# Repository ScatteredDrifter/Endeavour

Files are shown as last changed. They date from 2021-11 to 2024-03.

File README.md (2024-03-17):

# Endeavour | 10 Ortho Keyboard

An orthogonal  10u keyboard heavily inspired by [kb_elmo`s QEZ](https://github.com/kb-elmo/QEZ)

Used License for this project :: [Cern Open Hardware](/LICENSE)
by Evelyn~ Scattered Drifter 

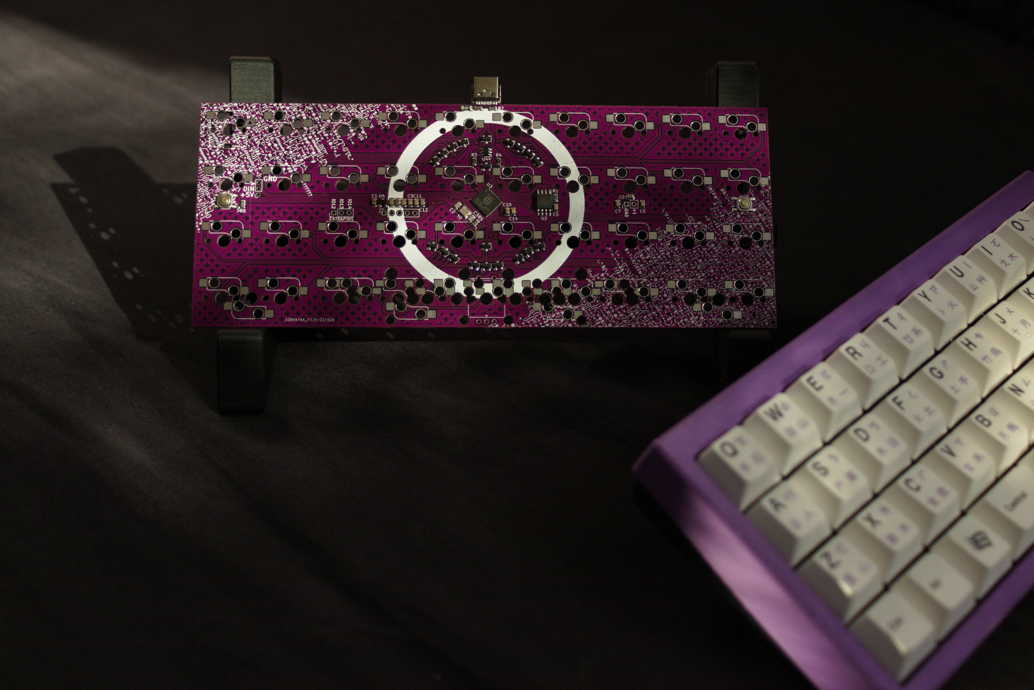
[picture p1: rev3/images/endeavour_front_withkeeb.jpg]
image of pcb with built keyboard


---

### Current Status: 

- rev3 tested, minor issues fixed in 
- firmware for QMK was updated to newest version, can be found [here](https://github.com/ScatteredDrifter/vial-qmk/tree/scatteredDriftersBoards/keyboards/scattereddrifter/endeavour)
- ZMK firmware pending
- rev3 case available - yet I dislike it in its current state.

---

## Endeavour V³ released //
The third iteration introduced a complete redesign of the pcb primarily to accommodate the **RP2040** and **BAV70 diodes**.

 I tried creating a circular positioning pattern for the components where their center is set with the mcu itself. Due to reposition of every component I rerouted the whole board again; also because Endeavour V¹ was one of my first designs and you can tell it was. A new silkscreen for both front and back of the pcb sets a different theme and clutters the whole board with ASCII-rubbish. This came into my mind because any actual drawing or pattern idea I had was blocked by my miserable ability to create art.

A new **case** accompanies this revision. Its not entirely done neither am I satisfied with its look and design. My abilities with CAD are limited and I lack the endurance ( will to use Windows or learn an alternative software) and time to make a better one or to create an actual good / decent design. 

Nevertheless my current process is shared in [this folder](/cases_rev3).
I've **tested the case** with a previous rev pcb and could verify that its mostly working. 
The new **case utilizes tadpole mount** of some sort hence I **ought to write a build guide**. 

For the previous versions of the **PCB** and **Case** look at the folders below:

2. [Rev2](/rev2/rev2.md)

### Features |- Rev3:
- support for two encoders ( top left)(bottom row middle)
- RP2040 
- 3 IO Pins exposed via breakout 
- pinout for led-strip (WS28 and similarly supported)
- QMK / VIAL support ( zmk should be possible too ) 
- different layout options
- new **case** with tadpole mount

#### Layout:

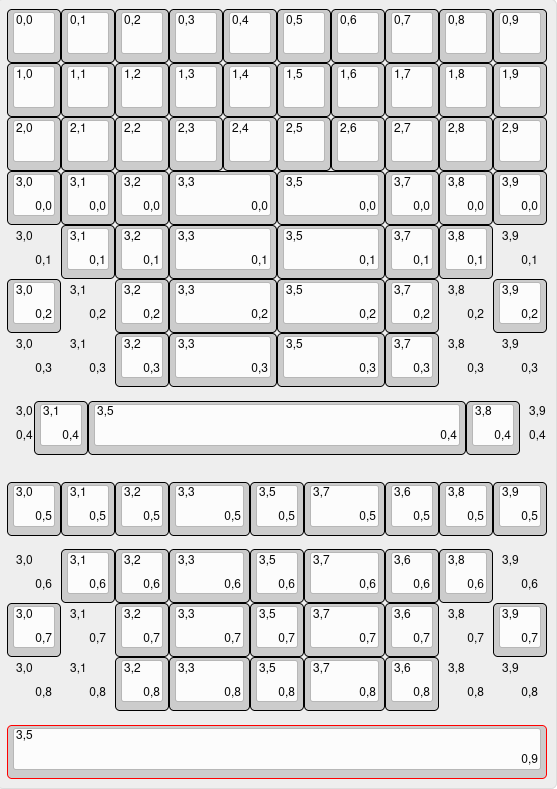
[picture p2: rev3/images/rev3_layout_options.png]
Image of available layouts in third revision


---

## Images 

### Images of V³ PCB:

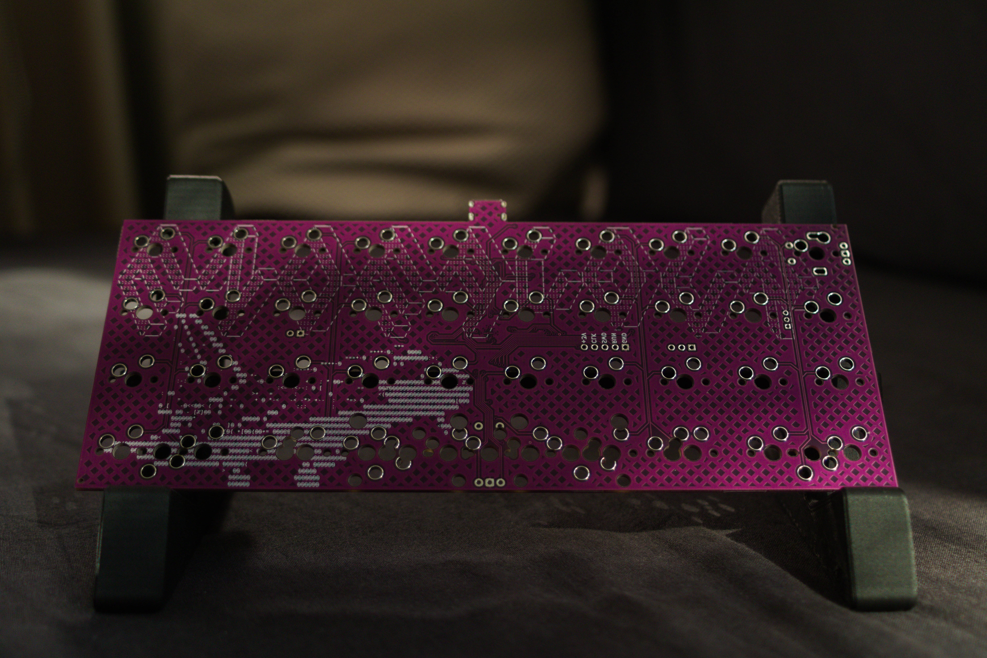
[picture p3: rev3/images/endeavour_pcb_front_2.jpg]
front image of pcb


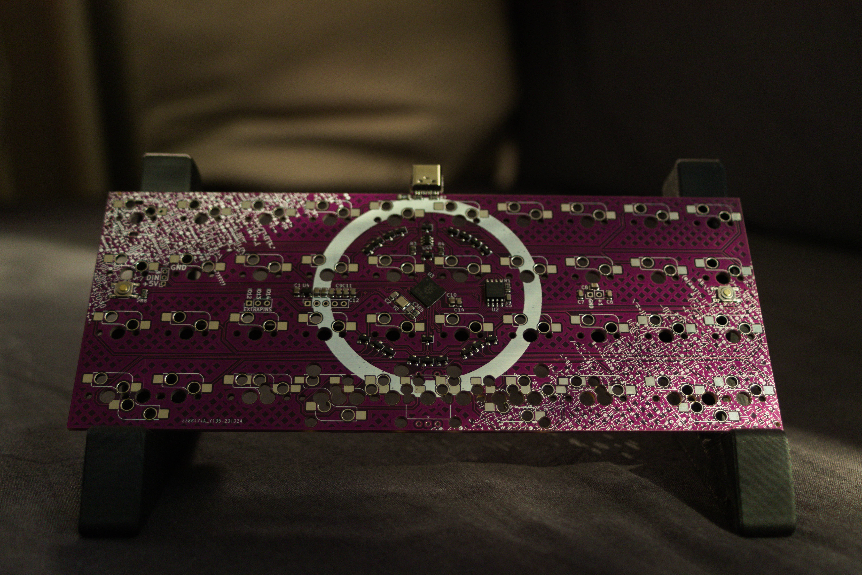
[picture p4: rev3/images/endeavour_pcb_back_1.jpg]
back image of pcb


### Images of V³ case:
Those are only renders, however I've printed a small test version already. 

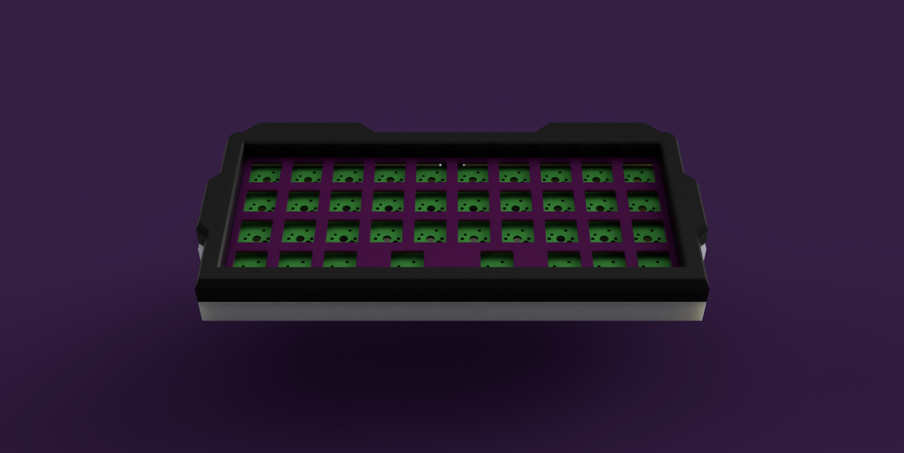
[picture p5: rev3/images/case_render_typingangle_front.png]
front image of keyboard case


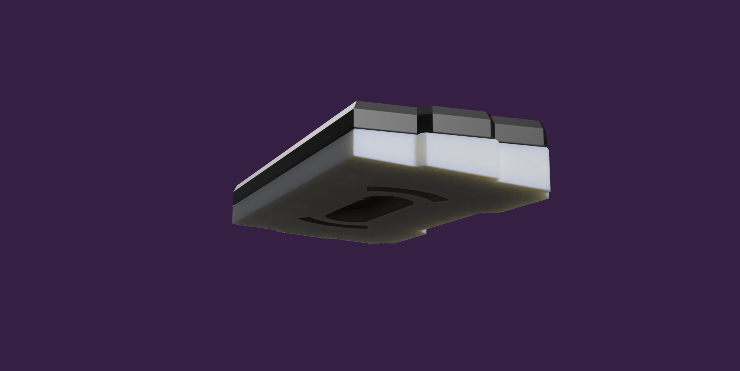
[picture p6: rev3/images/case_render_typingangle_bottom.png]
image of keyboard with typing angle


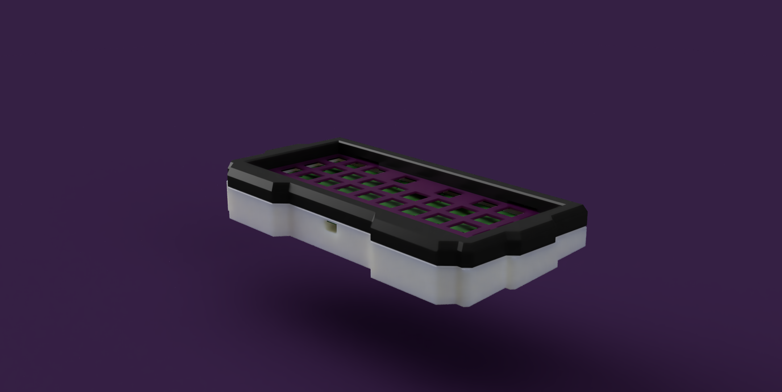
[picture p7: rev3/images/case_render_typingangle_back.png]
image of keyboard from side

---



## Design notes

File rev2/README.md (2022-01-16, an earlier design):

## ENDEAVOUR - REV2  PCB

An orthogonal 10u keyboard heavily inspired by [kb_elmo`s QEZ]([GitHub - kb-elmo/QEZ: A seamless, gasketmounted QAZ-like 40% keyboard](https://github.com/kb-elmo/QEZ))

---

### <u>Features:</u>

- Atmega32U2 as MCU

- north-facing Kailh-Hotswap support

- south-facing solder options

- USB-C

- 3d printed case with gasket mount

- options for WKL,HHKB, WKL+HHKB

- three bottom rows:
  
  - 1x 1u; 1x 7u; 1x 1u
  
  - 3x 1u; 2x 2u; 3x 1u
  
  - 3x 1u; 1x 1,5u; 1x 1u; 1x 1,5u; 3x 1u
  
  - image of possible bottom rows

- support for QMK+Vial/Via

- pinout to attach WSB28-Led-Strip (not yet supported in firmware)

## <u>Planned Features:</u>

- per-key RGB (not actively considered)

- wireless pcb 

## <u>CASE Images:</u>

---

This work is licensed under a [Creative Commons Attribution-NonCommercial-ShareAlike 4.0 International License](http://creativecommons.org/licenses/by-nc-sa/4.0/).



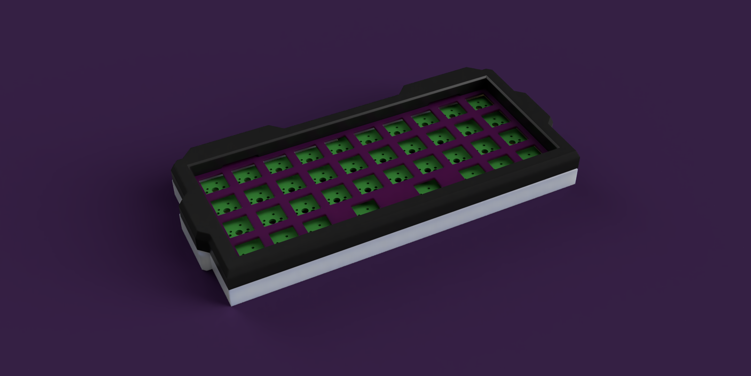
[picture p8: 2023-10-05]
rev3/images/case_render_front.PNG

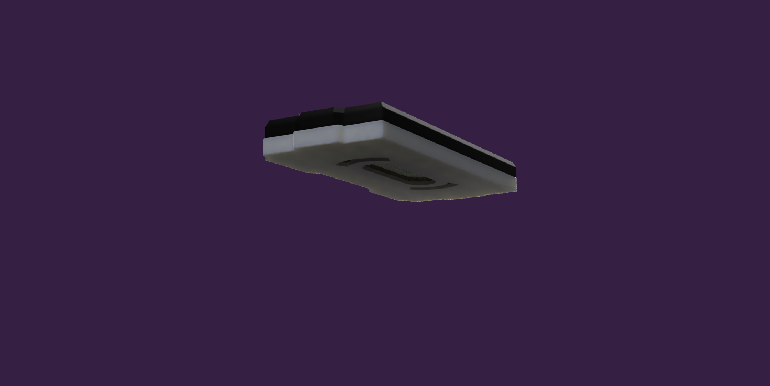
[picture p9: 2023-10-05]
rev3/images/case_render_bottom.PNG

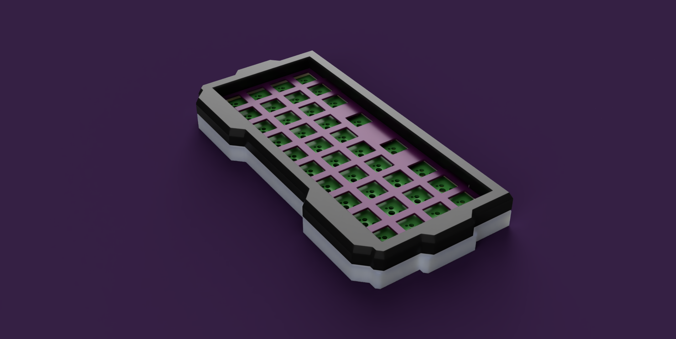
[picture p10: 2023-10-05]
rev3/images/case_render_side.PNG

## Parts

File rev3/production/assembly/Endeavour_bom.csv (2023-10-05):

Comment | Designator | Footprint | LCSC
1.5u | 1.5u1,1.5u2,1.5u3 | marbastlib-mx:SW_MX_HS_1u_NOREF
1u | K0,K1,K2,K3,K4,K5,K6,K7,K8,K9,K10,1u1,1u_space1,K11,1u2,1u_space2,K12,1u3,K13,1u4,K14,K15,1u6,K16,1u7,K17,1u8,K18,K19,K20,K21,K22,K23,K24,K25,K26,K27,K28,K29,1u4_offset1 | marbastlib-mx:SW_MX_HS_1u_NOREF
2u | 2u1,2u2,2u3,2u4,2u_1.25option1 | marbastlib-mx:SW_MX_HS_1u_NOREF
10u | C1,C4,C17 | Capacitor_SMD:C_0805_2012Metric | C91245
22pf | C2,C3 | Capacitor_SMD:C_0805_2012Metric | C1804
100n | C5,C6,C7,C9,C11,C12,C13,C14 | Capacitor_SMD:C_0805_2012Metric | C49678
1u | C8,C10 | Capacitor_SMD:C_0805_2012Metric | C28323
BAV70 | D1,D2,D3,D4,D5,D6,D7,D8,D9,D10,D11,D12,D13,D14,D15,D16,D17,D18,D19,D20 | Package_TO_SOT_SMD:SOT-23 | C181110
polyfuse | F0 | Fuse:Fuse_1206_3216Metric | C69688
BREAKOUT | J0 | Connector_PinSocket_2.54mm:PinSocket_1x05_P2.54mm_Vertical
USB_C_Receptacle_USB2.0 | J1 | Connector_USB:USB_C_Receptacle_HRO_TYPE-C-31-M-12 | C165948
Conn_01x03_Male | J2 | Connector_PinSocket_2.00mm:PinSocket_1x03_P2.00mm_Vertical
3x Breakout | additional pins | J3 | Connector_PinHeader_2.54mm:PinHeader_1x03_P2.54mm_Vertical
Breakout 1.1v | J4 | Connector_PinHeader_2.54mm:PinHeader_1x02_P2.54mm_Vertical
1k | R1,R5 | Resistor_SMD:R_0805_2012Metric | C115316
27 | R3,R4 | Resistor_SMD:R_0805_2012Metric | C104170
5.1k | R6,R7 | Resistor_SMD:R_0805_2012Metric | C27834
10k | R8 | Resistor_SMD:R_0805_2012Metric | C115309
7u | SPACE1 | marbastlib-mx:SW_MX_HS_1u_NOREF
RESET | SW0 | Keebio-Parts:SW_SPST_TL3342 | C2886894
RotaryEncoder_Switch | SW1,SW3 | marbastlib-various:ROT_Alps_EC11E-Switch
RESET | SW2 | Keebio-Parts:SW_SPST_TL3342 | C2886894
W25Q128JVS | U2 | Package_SO:SOIC-8_5.23x5.23mm_P1.27mm | C97521
RP2040 | U3 | RP2040:RP2040-QFN-56 | C2040
XC6206P Smaller footprint, less mA ~.5 | U4 | Package_TO_SOT_SMD:SOT-23 | C347376
SRV05-4 | U44 | Package_TO_SOT_SMD:SOT-23-6 | C85364
12MHZ Crystal | Y0 | Crystal:Crystal_SMD_3225-4Pin_3.2x2.5mm | C9002

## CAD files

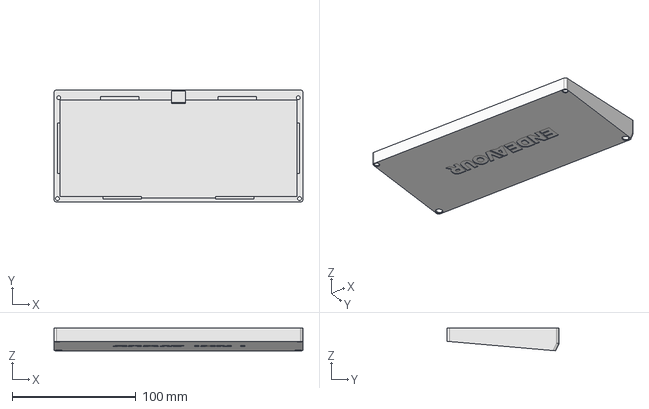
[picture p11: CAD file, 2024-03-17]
case_rev2/files-for-fusion/ichweine.FCStd
201.5 x 90.7 x 18.3 mm

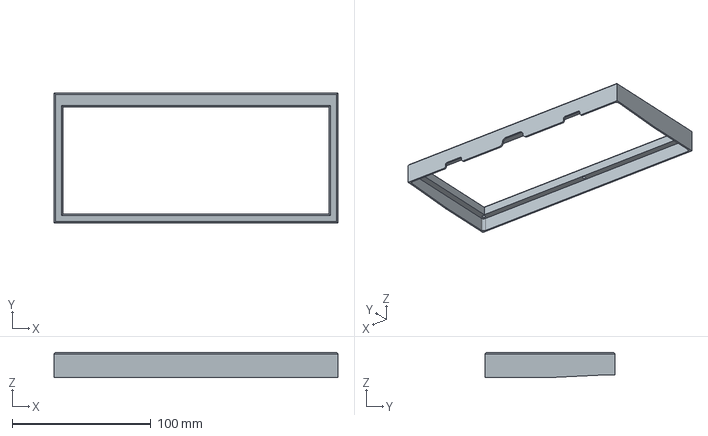
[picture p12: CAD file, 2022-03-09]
case_rev2/files-for-printing/rev5/top.step
204.5 x 93.7 x 18.1 mm

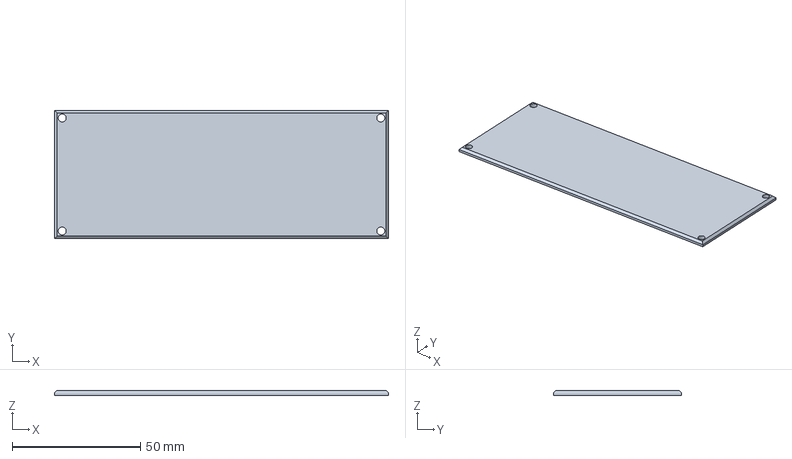
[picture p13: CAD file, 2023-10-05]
cases_rev3/Weight.3mf
130.0 x 50.0 x 2.00 mm

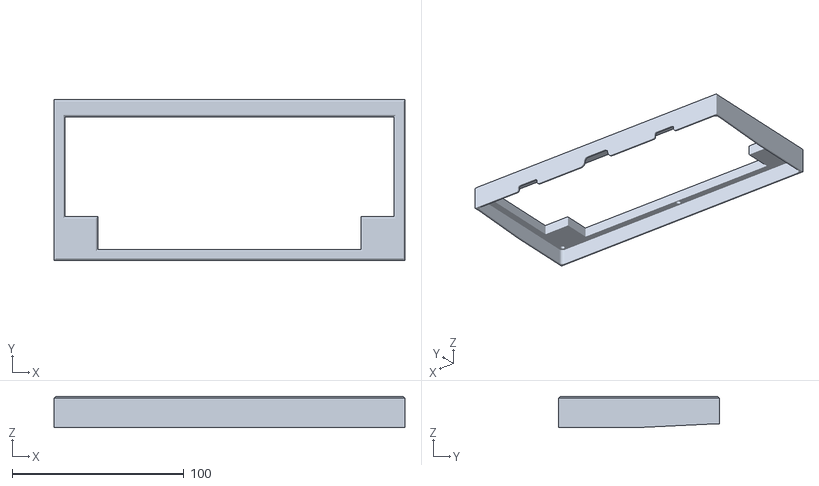
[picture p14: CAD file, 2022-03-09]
case_rev2/files-for-printing/rev5/top-hhkb.stl
204.5 x 93.7 x 18.1

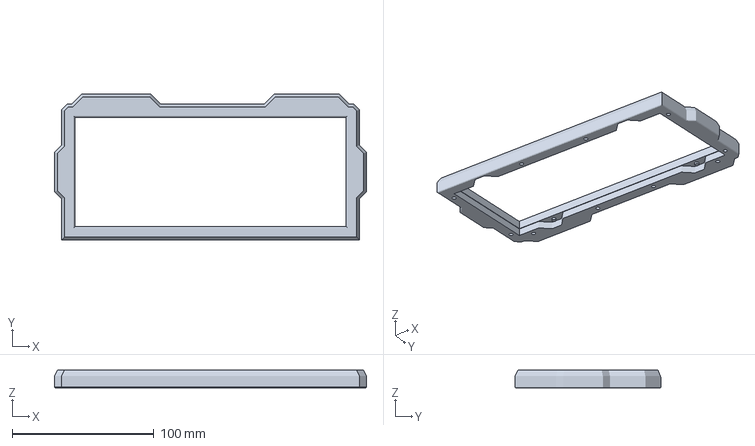
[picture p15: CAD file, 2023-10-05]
cases_rev3/Top-Case.3mf
220.2 x 102.9 x 12.5 mm

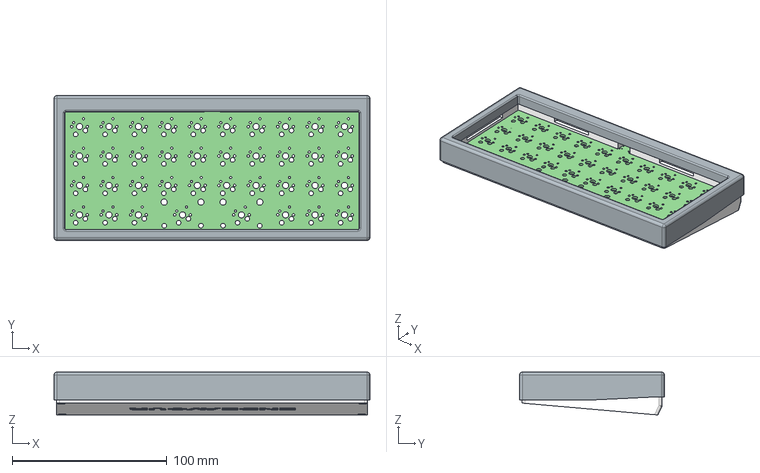
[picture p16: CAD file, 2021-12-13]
case_rev2/files-for-fusion/endeavourcase v32.step
204.5 x 93.7 x 27.8 mm
DX07S024JJ2R1300

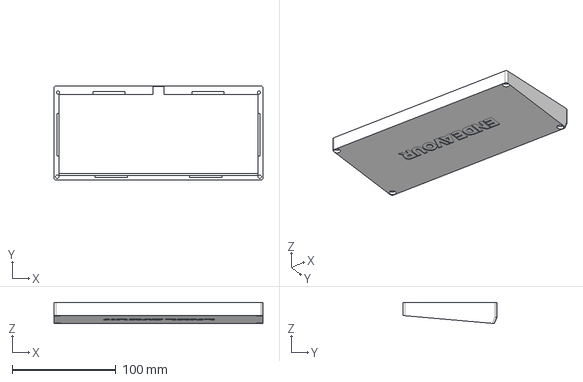
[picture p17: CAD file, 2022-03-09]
case_rev2/files-for-printing/rev5/bottomcase.step
201.5 x 90.7 x 20.3 mm

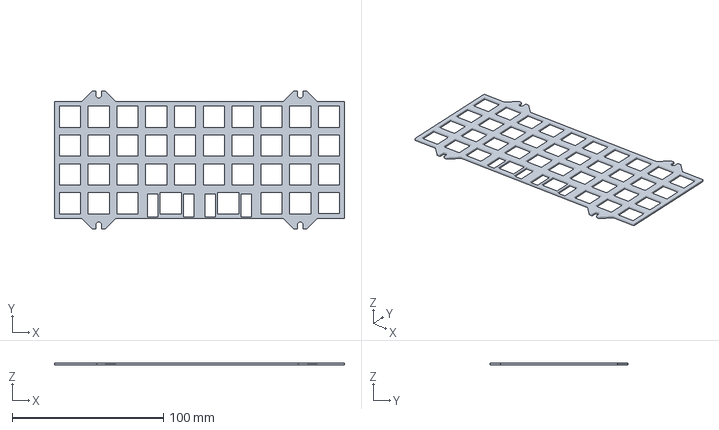
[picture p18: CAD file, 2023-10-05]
cases_rev3/plate_2x2U.3mf
191.8 x 91.5 x 1.50 mm

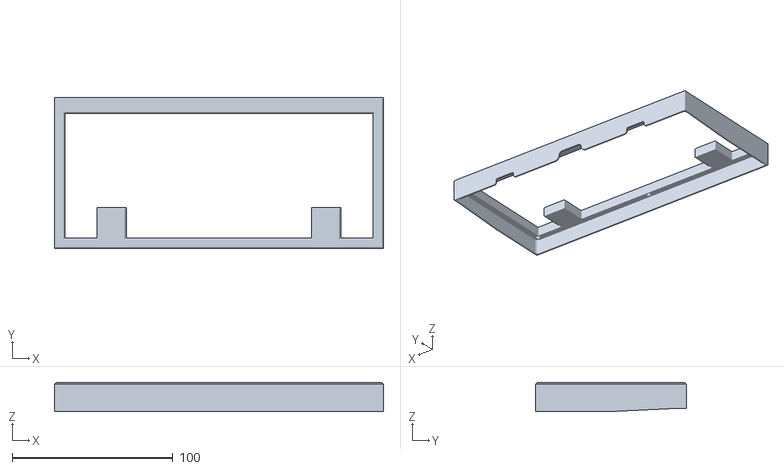
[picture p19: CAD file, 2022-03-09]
case_rev2/files-for-printing/rev5/top-wkl.stl
204.5 x 93.7 x 18.1

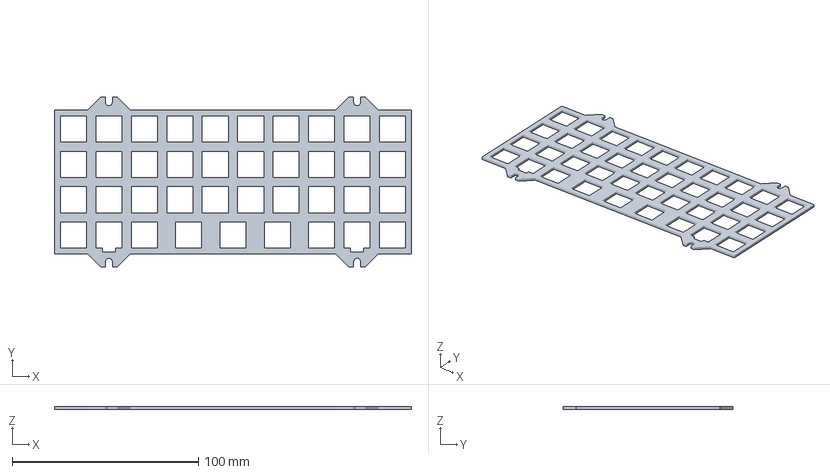
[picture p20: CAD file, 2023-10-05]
cases_rev3/plate2x1.5U.3mf
191.8 x 91.5 x 1.60 mm

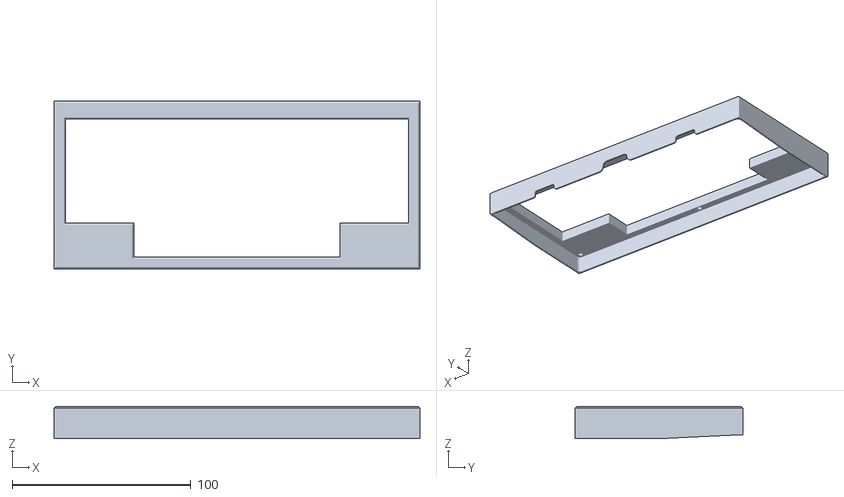
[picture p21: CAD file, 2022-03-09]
case_rev2/files-for-printing/rev5/top-hhkb+wkl.stl
204.5 x 93.7 x 18.1

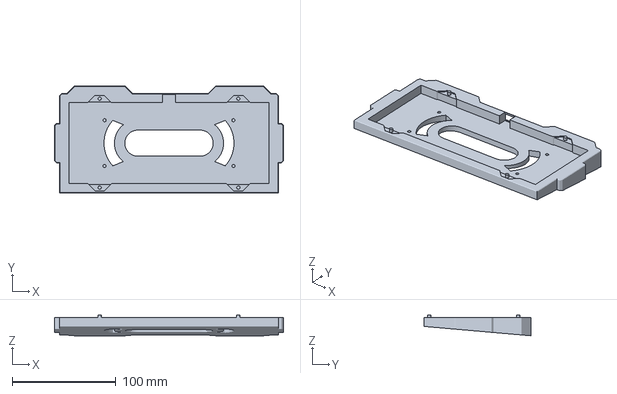
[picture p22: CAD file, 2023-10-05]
cases_rev3/bottom-case.3mf
220.2 x 102.9 x 19.8 mm

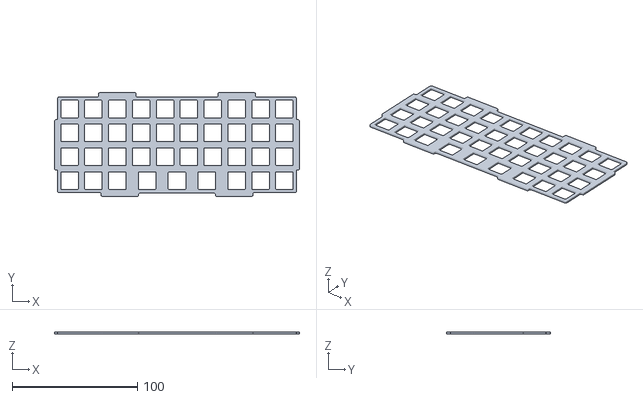
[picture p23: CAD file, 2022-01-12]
case_rev2/files-for-printing/rev5/plate-alternative-bottom2.stl
195.5 x 82.7 x 1.60

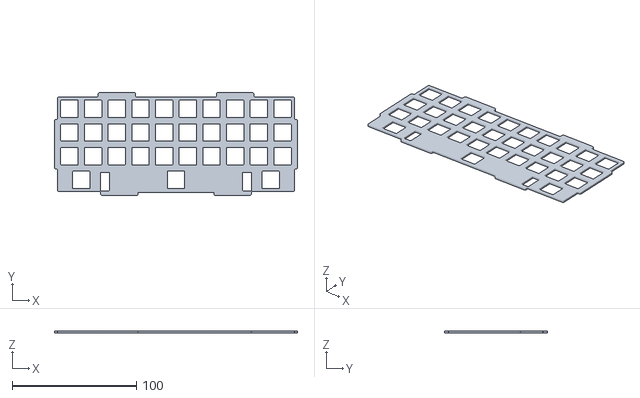
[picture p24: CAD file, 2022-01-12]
case_rev2/files-for-printing/rev5/plate-alternative-bottom1.stl
195.5 x 82.7 x 1.60

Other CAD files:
case_rev2/files-for-printing/rev5/plate.stl
case_rev2/files-for-printing/rev4/top-hhkb+wkl.stl
case_rev2/files-for-fusion/endeavourcase v31.step
case_rev2/files-for-printing/rev4/plate.stl
case_rev2/files-for-printing/rev4/bottomcase.stl
case_rev2/files-for-printing/rev4/top.stl
case_rev2/files-for-printing/rev5/bottomcase.stl
case_rev2/files-for-printing/rev5/top.stl

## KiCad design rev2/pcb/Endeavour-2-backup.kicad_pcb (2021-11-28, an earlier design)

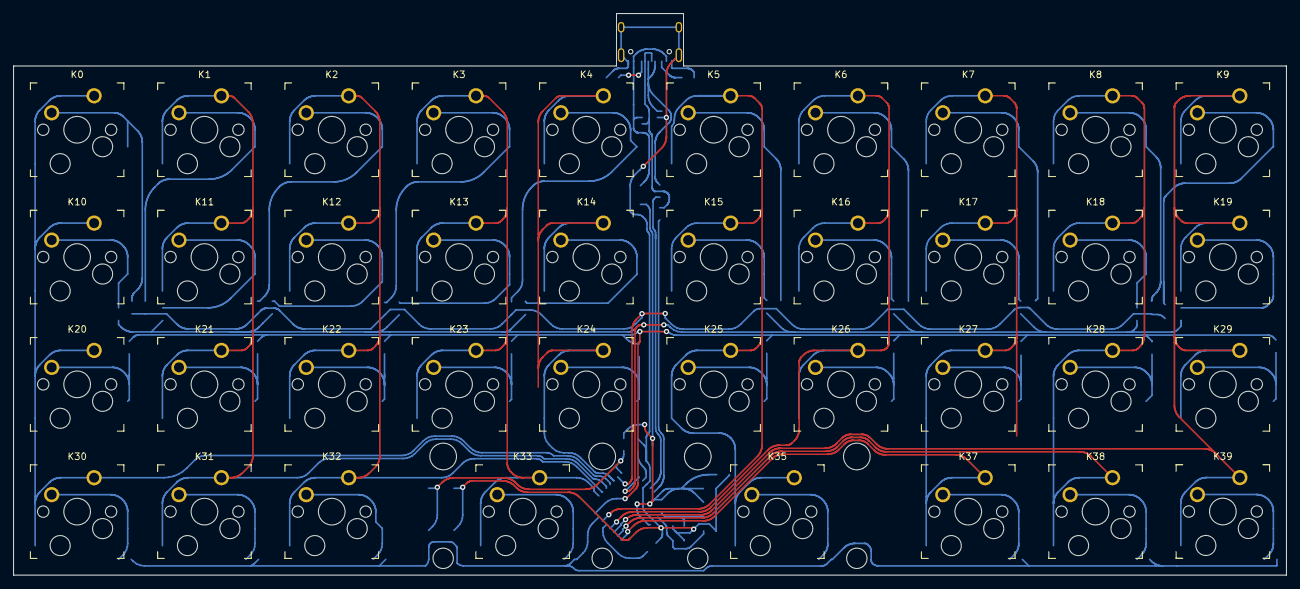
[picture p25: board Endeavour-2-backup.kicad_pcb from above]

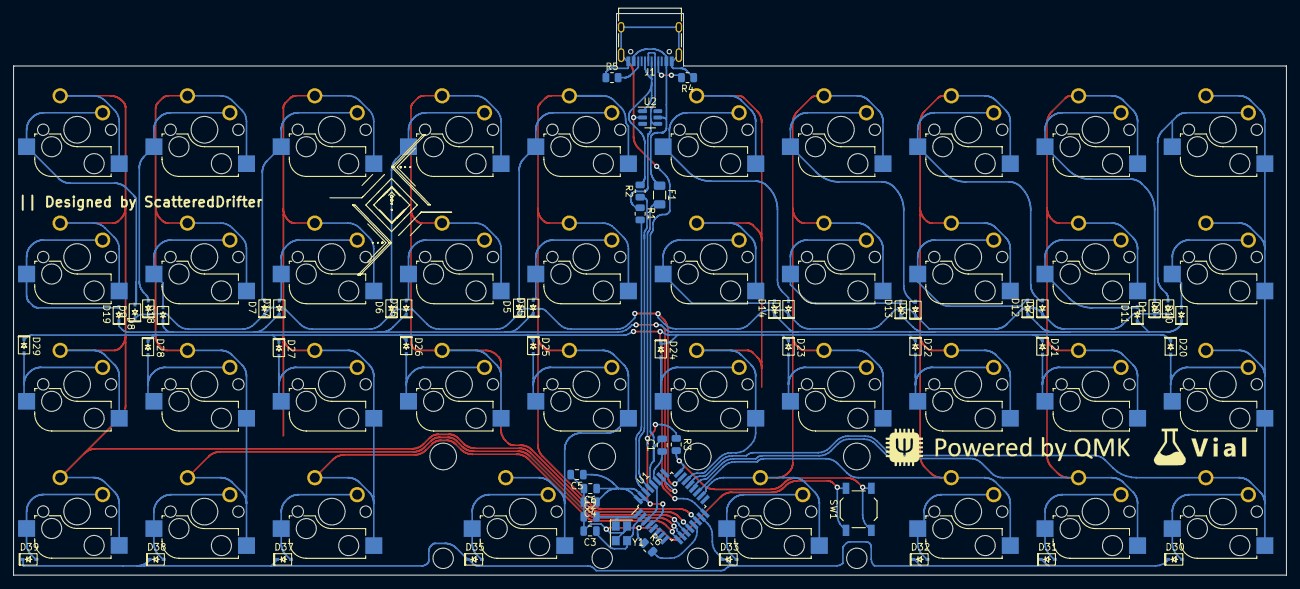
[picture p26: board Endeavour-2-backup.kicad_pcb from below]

Board: 2 copper layers, 190.5 x 84.0 mm, 94 parts (56 on the bottom side), 66 nets.

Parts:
C1: 1uF; C_0805_2012Metric
C2, C3: 22pF; C_0805_2012Metric
C4, C6: 0.1uF; C_0805_2012Metric
C5: 10uF; C_0805_2012Metric
D0, D1, D2, D3, D4, D5, D6, D7, D8, D9, D10, D11, D12, D13, D14, D15, D16, D17, D18, D19, D20, D21, D22, D23, D24, D25, D26, D27, D28, D29, D30, D31, D32, D33, D35, D37, D38, D39: 1N4448; D_SOD-323
F1: Polyfuse_Small; Fuse_1206_3216Metric
J1: USB_C_Receptacle_USB2.0; USB_C_Receptacle_HRO_TYPE-C-31-M-12
K0, K1, K2, K3, K4, K5, K6, K7, K8, K9, K10, K11, K12, K13, K14, K15, K16, K17, K18, K19, K20, K21, K22, K23, K24, K25, K26, K27, K28, K29, K30, K31, K32, K33, K35, K37, K38, K39: KEYSW; Kailh_socket_MX_optional
R1, R2: 22; R_0805_2012Metric
R3, R6: 10k; R_0805_2012Metric
R4, R5: 5,1k; R_0805_2012Metric
SW1: SW_PUSH; SW_SPST_TL3342
U1: ATmega32U2-A; TQFP-32_7x7mm_P0.8mm
U2: SRV05-4; SOT-23-6
Y1: Crystal_GND24_Small; Crystal_SMD_3225-4Pin_3.2x2.5mm

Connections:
+5: C4.1, C5.1, C6.1, F1.2, R3.1, U1.4, U1.31, U1.32
D+: J1.A6, J1.B6, R2.2, U2.1
D-: J1.A7, J1.B7, R1.1, U2.4
GND: C1.2, C2.1, C3.2, C4.2, C5.2, C6.2, J1.A1, J1.A12, J1.B1, J1.B12, J1.S1, R4.1, R5.1, R6.1, SW1.1, U1.3, U1.28, U2.2, Y1.2, Y1.4
unnamed: C1.1, U1.27
unnamed: C2.2, U1.1, Y1.1
unnamed: C3.1, U1.2, Y1.3
unnamed: D0.2, K0.2
unnamed: D1.2, K1.2
unnamed: D2.2, K2.2
unnamed: D3.2, K3.2
unnamed: D4.2, K4.2
unnamed: D5.2, K5.2
unnamed: D6.2, K6.2
unnamed: D7.2, K7.2
unnamed: D8.2, K8.2
unnamed: D9.2, K9.2
unnamed: D10.2, K10.2
unnamed: D11.2, K11.2
unnamed: D12.2, K12.2
unnamed: D13.2, K13.2
unnamed: D14.2, K14.2
unnamed: D15.2, K15.2
unnamed: D16.2, K16.2
unnamed: D17.2, K17.2
unnamed: D18.2, K18.2
unnamed: D19.2, K19.2
unnamed: D20.2, K20.2
unnamed: D21.2, K21.2
unnamed: D22.2, K22.2
unnamed: D23.2, K23.2
unnamed: D24.2, K24.2
unnamed: D25.2, K25.2
unnamed: D26.2, K26.2
unnamed: D27.2, K27.2
unnamed: D28.2, K28.2
unnamed: D29.2, K29.2
unnamed: D30.2, K30.2
unnamed: D31.2, K31.2
unnamed: D32.2, K32.2
unnamed: D33.2, K33.2
unnamed: D35.2, K35.2
unnamed: D37.2, K37.2
unnamed: D38.2, K38.2
unnamed: D39.2, K39.2
unnamed: J1.A5, R4.2
unnamed: J1.B5, R5.2
unnamed: R1.2, U1.30
unnamed: R2.1, U1.29
unnamed: R3.2, SW1.2, U1.24
unnamed: R6.2, U1.13
VCC: F1.1, J1.A4, J1.A9, J1.B4, J1.B9, U2.5
col0: K0.1, K10.1, K20.1, K30.1, U1.21
col1: K1.1, K11.1, K21.1, K31.1, U1.20
col2: K2.1, K12.1, K22.1, K32.1, U1.19
col3: K3.1, K13.1, K23.1, K33.1, U1.18
col4: K4.1, K14.1, K24.1, U1.22
col5: K5.1, K15.1, K25.1, K35.1, U1.14
col6: K6.1, K16.1, K26.1, U1.12
col7: K7.1, K17.1, K27.1, K37.1, U1.9
col8: K8.1, K18.1, K28.1, K38.1, U1.10
col9: K9.1, K19.1, K29.1, K39.1, U1.11
row0: D0.1, D1.1, D2.1, D3.1, D4.1, D5.1, D6.1, D7.1, D8.1, D9.1, U1.23
row1: D10.1, D11.1, D12.1, D13.1, D14.1, D15.1, D16.1, D17.1, D18.1, D19.1, U1.26
row2: D20.1, D21.1, D22.1, D23.1, D24.1, D25.1, D26.1, D27.1, D28.1, D29.1, U1.16
row3: D30.1, D31.1, D32.1, D33.1, D35.1, D37.1, D38.1, D39.1, U1.15

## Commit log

2021-11-28 added pcb, case and firmware files
    [bottomcase.stl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]
2021-12-01 updated case, fixed screw hole and included .step
    [bottomcase.stl, endeavourcase v27.step, plate.stl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]
2021-12-03 updated case, fixed minor issues regarding dimensions of bottomcase
    [bottomcase.stl, endeavourcase v28.f3z, endeavourcase v28.step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]
2021-12-11 updated README,new images,updated case, added wkl,hhkb,megahhkb options
    [bottomcase.stl, plate.stl, top-hhkb+wkl.stl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]
2021-12-12 added new bottom row options
    [19b49bfbb8c4258b4422eb325fa9a4ba14adc311_switch.dxf]
2021-12-13 updated version of case - 5mm spacing between case and pcb, better screw placement,
    [bottomcase.stl, endeavourcase v27.step, endeavourcase v28.f3z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]
2021-12-14 updated case to REV5.1
    [bottomcase.stl, plate.stl, top.stl]
2022-01-12 added plates for layouts
    [plate-alternative-bottom1.stl, plate-alternative-bottom2.stl]
2022-01-15 updated pcb to rev2, added new bom,gerber,pos; firmware for rev2
    [19b49bfbb8c4258b4422eb325fa9a4ba14adc311_switch.dxf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]
2022-01-16 added 10 u support for vial
    [Endeavour-2old-routing.kicad_pcb]
2022-03-09 fixed kle and firmware
    [19b49bfbb8c4258b4422eb325fa9a4ba14adc311_switch.dxf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]
2022-04-03 declustered, updated firmware folders
    [endeavourcase v31.step]
2023-04-02 added pcb based on rp2040
    - updated footprints to hotswap only
    - silkscreen not done yet
    - new positioning of diode cluster, updated to BAV70 diodes
    - further bottom-row options included
    [Endeavour-2-B_Cu.gbr, Endeavour-2-B_Mask.gbr, Endeavour-2-B_Paste.gbr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]
2023-10-05 added new 3dp-case, updated pcb to rp204 and more
    [Endeavour-2-B_Cu.gbr, Endeavour-2-B_Mask.gbr, Endeavour-2-B_Paste.gbr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]
2023-11-19 update readme, add images of pcb and update information
2024-03-17 fix overlapping footprint, add legends for bottom row
    [Endeavour-2.kicad_sch]
2024-03-17 reorganize repo, remove unused assets
    [19b49bfbb8c4258b4422eb325fa9a4ba14adc311_switch.dxf, Top-Case.3mf, Weight.3mf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]
2024-03-17 update readme, fix typos
    [Top-Case.3mf, Weight.3mf, bottom-case.3mf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]

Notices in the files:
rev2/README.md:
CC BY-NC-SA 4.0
